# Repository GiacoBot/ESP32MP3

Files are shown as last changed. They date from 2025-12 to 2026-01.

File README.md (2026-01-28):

# **ESP32 MP3**

A self-built, portable MP3 player based on ESP32, combining a custom hardware design with an intuitive software interface. It reads music from an SD card, streams audio to any Bluetooth audio device, and is controlled via an OLED display and physical buttons.

<p align="center">
Project Photo
</p>

## **Introduction**

This project evolved from a simple software experiment. The initial version was merely a proof-of-concept for Bluetooth audio streaming from an ESP32. Driven by the desire to create a complete and presentable product, I designed and built a custom dev board, developing an entire graphical and physical user interface from scratch.

The result is a functional and integrated device, demonstrating expertise in both hardware design (PCB design with KiCad) and complex firmware development (modular C++ architecture).

## **✨ Key Features**

#### **Hardware**

*   **Custom Dev Board (Rev 1.1)**: Development board entirely designed with KiCad to house all components compactly and functionally.
*   **0.96" OLED Display**: Monochrome screen (SSD1306 128x64) for a clear, low-power user interface.
*   **Physical Controls**: Interface navigation is managed by 5 physical buttons (Up, Down, Left, Right, Enter).
*   **MicroSD Card Storage**: A MicroSD card slot allows easy loading and playback of your music library.
*   **Power Management**: Power circuit with support for Li-Ion batteries and USB-C charging.

#### **Software**

*   **Bluetooth Audio Streaming (A2DP Source)**: Connects to Bluetooth headphones and speakers for high-quality wireless playback.
*   **Multi-screen User Interface**:
    *   **Bluetooth Device Selection**: Scans for nearby audio devices and manages the connection.
    *   **Track Selection**: Allows browsing the complete playlist of songs on the SD Card.
    *   **Now Playing**: Displays track information (if available), song title, artist, and a progress bar.
    *   **Volume Control**: Adjusts the playback volume directly from the interface.
*   **Advanced Playlist Management**: Automatically scans the SD card on startup to find all `.mp3` files.
*   **Intuitive User Input**: Supports short press, long press, and auto-repeat of buttons for smooth and fast navigation.
*   **Modular Firmware Architecture**: The code is organized into specialized "Managers" (Display, Input, Bluetooth, Player), making the system scalable, maintainable, and easy to debug.

## **⚙️ Hardware Details**

The development board was designed in KiCad to integrate the ESP32 with all necessary modules. The design is optimized for manual assembly and for use as a portable device.

<p align="center">
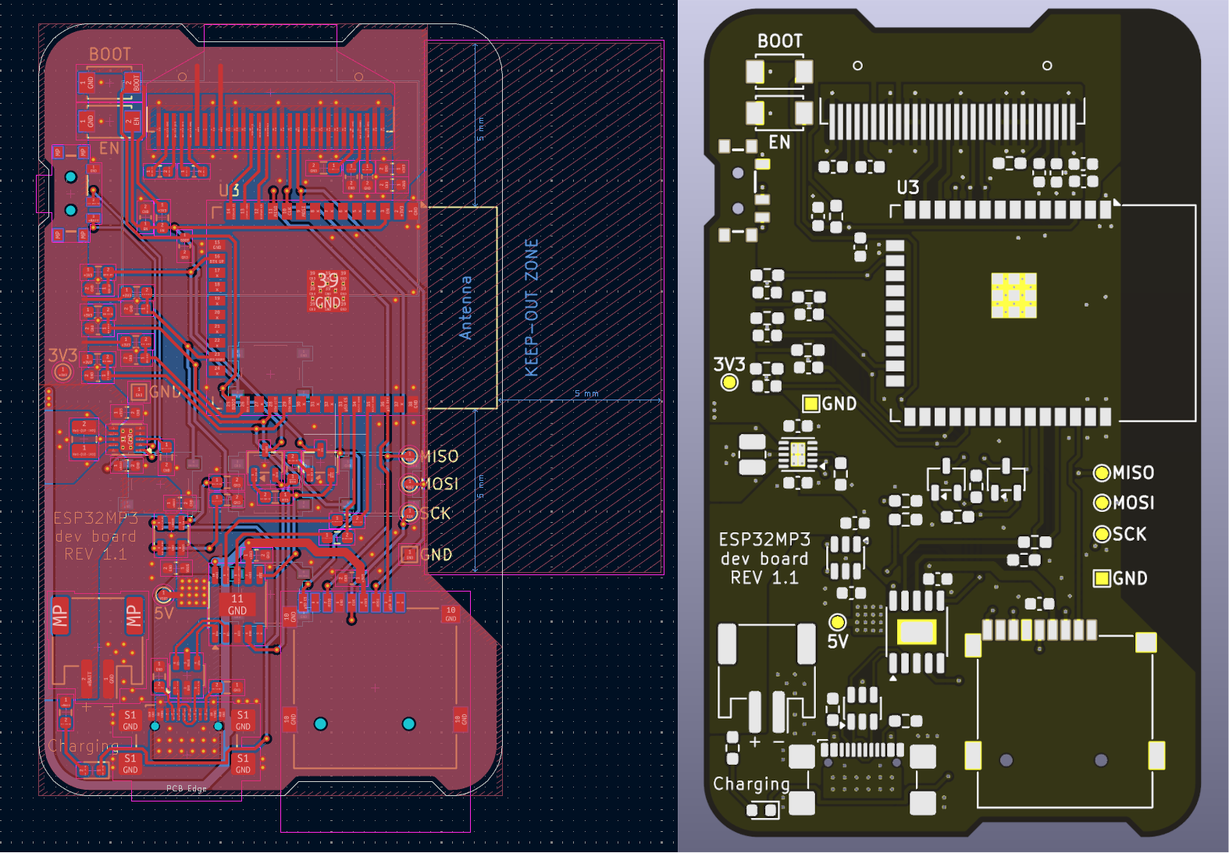
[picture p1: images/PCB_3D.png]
Project Photo

</p>

*   **Design Software**: KiCad
*   **Main Processor**: ESP32-WROOM-32E module
*   **Display**: 0.96 inch (128x64) SSD1306 I2C/SPI OLED module
*   **Storage**: Standard MicroSD card reader
*   **Hardware Repository**: KiCad project files (schematics, PCB, and libraries) are available in the [`/Hardware/devboard Rev1.1`](/Hardware/devboard%20Rev1.1/) folder.

## **💻 Software Details**

The firmware is developed using the Arduino framework within PlatformIO, which simplifies dependency management and compilation.

*   **Framework**: Arduino / PlatformIO
*   **Key Libraries**:
    *   **[`U8g2`](https://github.com/olikraus/U8g2)**: Excellent library for managing monochrome displays.
    *   **[`arduino-audio-tools`](https://github.com/pschatzmann/arduino-audio-tools)**: For the audio decoding and processing pipeline.
    *   **[`ESP32-A2DP`](https://github.com/pschatzmann/ESP32-A2DP)**: For implementing the Bluetooth A2DP Source stack.
    *   **[`arduino-libhelix`](https://github.com/pschatzmann/arduino-libhelix)**: Provides the MP3 decoder based on Helix.
*   **Architecture**: The heart of the software is a state machine that manages navigation between different screens (`AppScreen`). The logic is divided into independent manager classes that communicate via an event system (`InputEvent`) and shared states, ensuring high cohesion and low coupling between modules.

## **🚀 Getting Started**

> [!NOTE]  
> If you want to try a simplified version of the project, you can try the alpha version, a proof of concept that only requires a breakout module for the micro SD and an ESP32 board. Follow the `README` in the alpha version for instructions.

#### **1. Hardware Prerequisites**

*   The assembled Dev Board.
*   A MicroSD card formatted as FAT32 and loaded with `.mp3` files. Is required for the files to have a sample rate of 44100 Hz, use the following `ffmpeg` command to convert files if needed:

    ```bash
    ffmpeg -i input.mp3 -ar 44100 output.mp3
    ```
*   A USB-C cable to upload the firmware.

#### **2. Software Setup**

The project is designed to be compiled with PlatformIO in Visual Studio Code.

1.  **Install VS Code and PlatformIO**: Follow the [official PlatformIO guide](https://platformio.org/install/ide?install=vscode).
2.  **Clone the Repository**:
    ```bash
    git clone https://github.com/GiacoBot/ESP32MP3.git
    cd ESP32MP3
    ```
3.  **Initialize Submodules**: The audio libraries are included as Git submodules.
    ```bash
    git submodule update --init --recursive
    ```

#### **3. Compile and Upload**

1.  **Open the Project**: In VS Code, open the project folder. Make sure to open the `Software` subfolder.
> [!IMPORTANT]  
> The PlatformIO project is located within the `Software` folder. When you open this project in VS Code, make sure you open the `Software` directory, not the root of the repository, to ensure PlatformIO can find all the necessary files.

1.  **Change Board settings**: Modify the `src/settings.h` file to match your hardware configuration if necessary (e.g., pin assignments).
2.  **Compile and Upload**: Use the PlatformIO commands (down arrow on the status bar) to build and upload the firmware to the board.

## **📸 Gallery**

Various screenshots of the user interface:

<p align="center">
Project Photo
</p>

## **📜 License**

This project is released under the GPL-3.0 License. See the [LICENSE](LICENSE) file for more details.

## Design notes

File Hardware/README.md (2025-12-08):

# Hardware

This folder contains the hardware design files for the project's custom development board.
Each hardware revision is organized in its own subfolder to keep designs clean, traceable, and easy to reference.

### Dev boards

* **Devboard Rev1.0** – First prototype of the dev board. Includes schematics, PCB layout, Gerber files, and BOM.
* **Devboard Rev1.1** – Updated revision addressing small issues found in Rev1.0. Recommended for new builds.

The development board is a semi-finished prototype, created to also validate the electrical design of the battery-charging circuitry and the buck-boost voltage regulation stage.
Its purpose is to verify the power system and provide a convenient and compact development board.

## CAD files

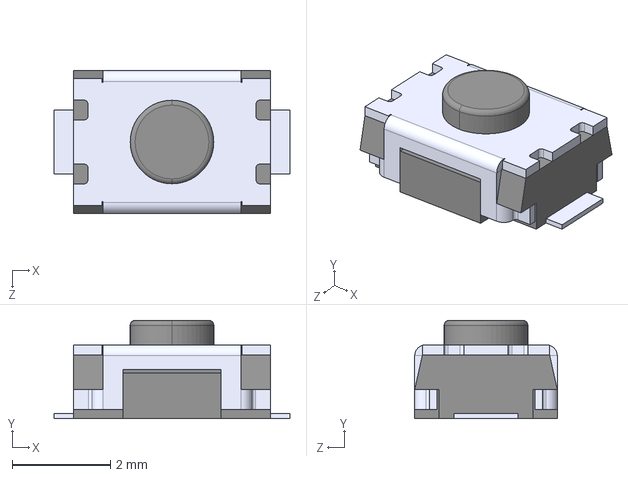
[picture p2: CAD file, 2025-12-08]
Hardware/devboard Rev1.1/Library.3dmodels/TS-1088-AR02016.step
4.80 x 2.00 x 2.90 mm

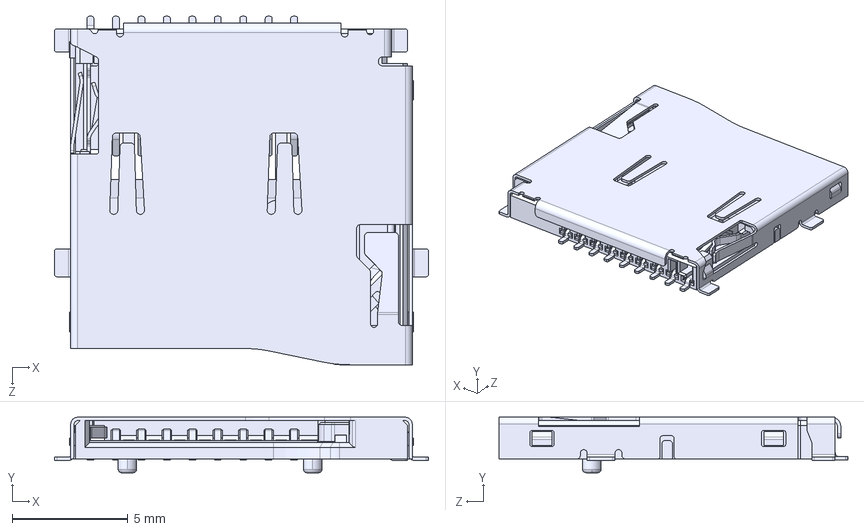
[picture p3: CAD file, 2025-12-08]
Hardware/devboard Rev1.1/Library.3dmodels/TF_PUSH.step
16.1 x 2.40 x 15.0 mm

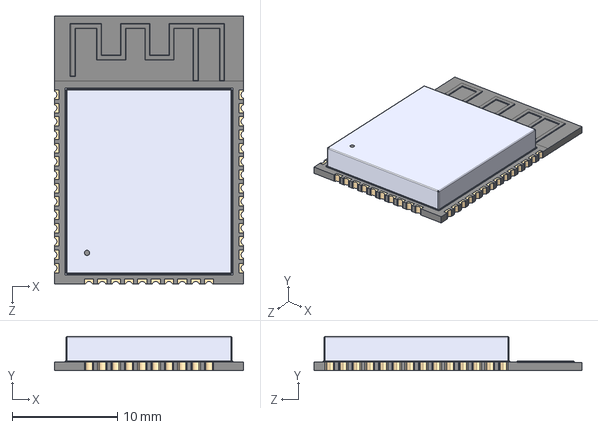
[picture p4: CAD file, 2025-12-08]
Hardware/devboard Rev1.1/Library.3dmodels/ESP32-WROOM-32E-N8.STEP
18.0 x 3.25 x 25.5 mm

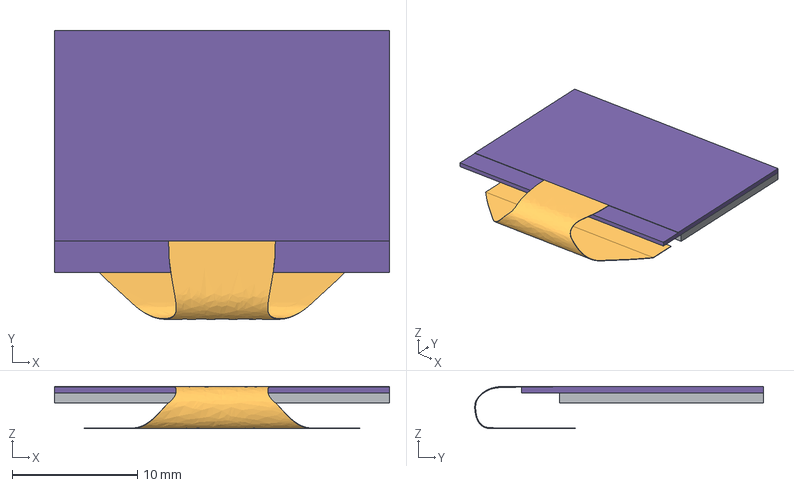
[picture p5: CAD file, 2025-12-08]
Hardware/devboard Rev1.1/Library.3dmodels/SSD1306_OLED_Display.step
26.7 x 23.0 x 3.35 mm

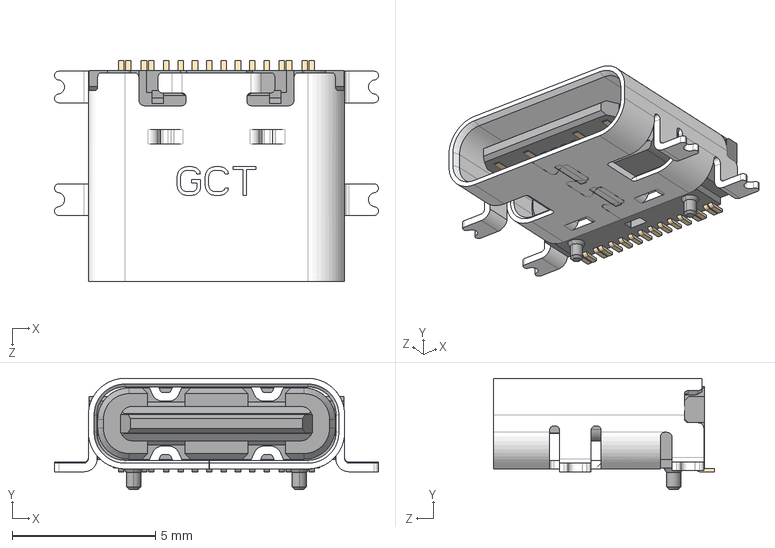
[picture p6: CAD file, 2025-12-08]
Hardware/devboard Rev1.1/Library.3dmodels/USBC.STEP
11.3 x 3.89 x 7.70 mm

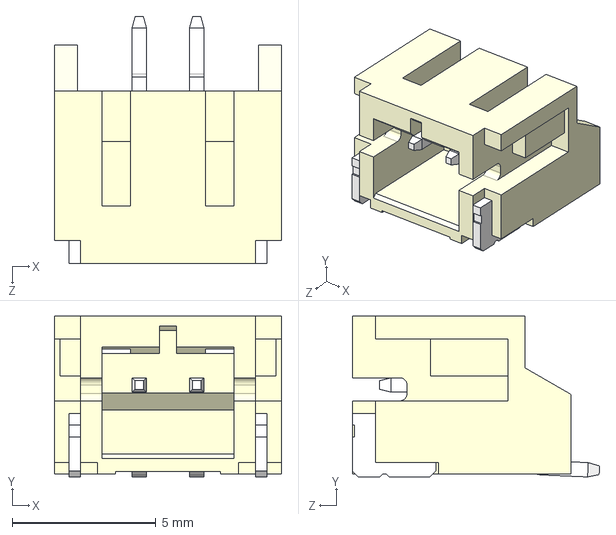
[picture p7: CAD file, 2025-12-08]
Hardware/devboard Rev1.1/Library.3dmodels/S2B-PH-SM4-TB.STEP
7.90 x 5.60 x 8.60 mm

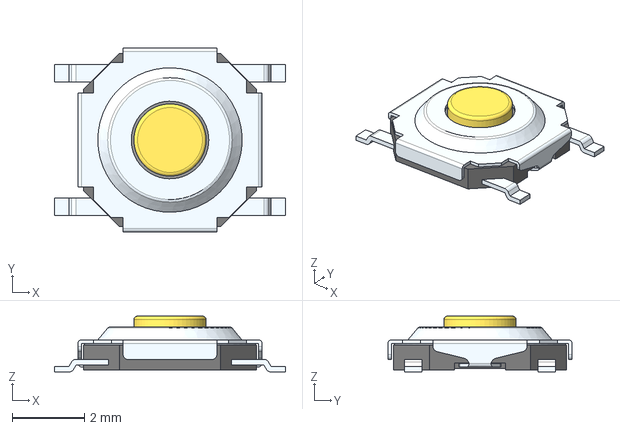
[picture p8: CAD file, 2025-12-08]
Hardware/devboard Rev1.1/Library.3dmodels/PTS526SK15SMTR2LFS.stp
6.40 x 5.10 x 1.55 mm

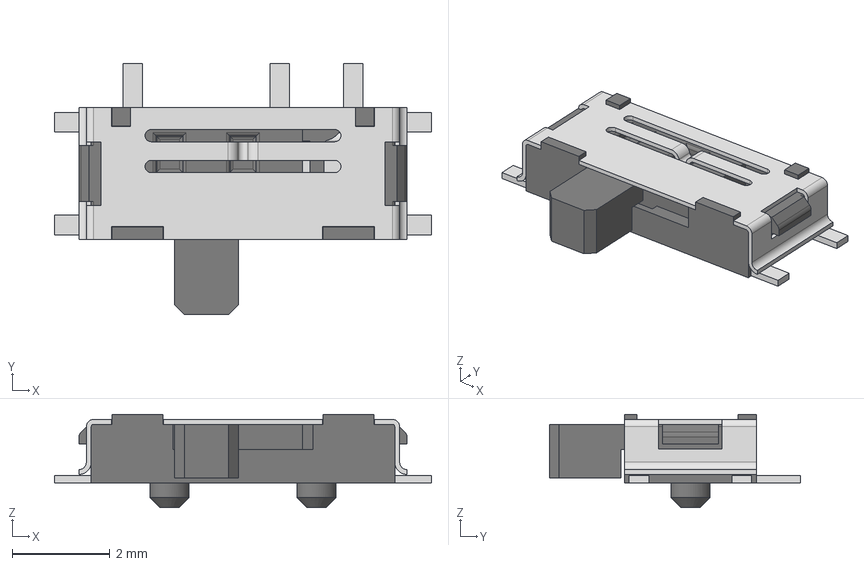
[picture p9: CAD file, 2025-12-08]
Hardware/devboard Rev1.1/Library.3dmodels/SWITCH SPDT.step
7.70 x 5.13 x 1.90 mm
Frame
Pin 4
Frame 1
Pin 1
Pin 2
Pin 3
Slider 1
Slider
Cover

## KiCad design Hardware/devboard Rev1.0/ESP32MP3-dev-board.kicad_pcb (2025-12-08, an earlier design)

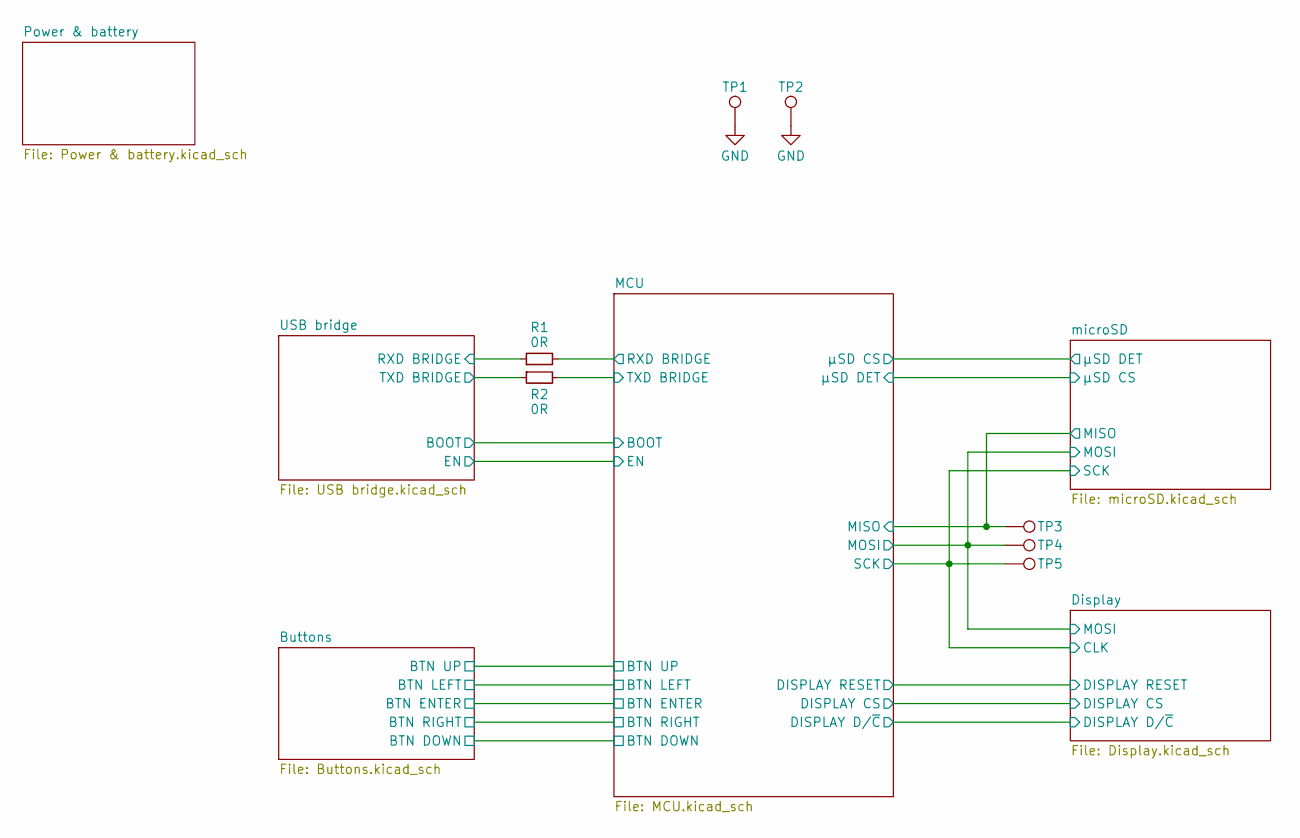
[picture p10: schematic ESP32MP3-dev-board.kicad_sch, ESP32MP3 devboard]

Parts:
R1, R2: 0R; R_0603_1608Metric_Pad0.98x0.95mm_HandSolder; Part Number YAGEO RC0603JR-070RL
TP1, TP2: GND; TestPoint_Pad_1.0x1.0mm
TP3: MISO; TestPoint_Pad_D1.0mm
TP4: MOSI; TestPoint_Pad_D1.0mm
TP5: SCK; TestPoint_Pad_D1.0mm

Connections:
/Display/CLK: TP5.1; also elsewhere on the board
/Display/MOSI: TP4.1; also elsewhere on the board
/MCU/MISO: TP3.1; also elsewhere on the board
/MCU/RXD BRIDGE: R1.2; also elsewhere on the board
/MCU/TXD BRIDGE: R2.2; also elsewhere on the board
/USB bridge/RXD BRIDGE: R1.1; also elsewhere on the board
/USB bridge/TXD BRIDGE: R2.1; also elsewhere on the board
GND: TP1.1, TP2.1; also elsewhere on the board

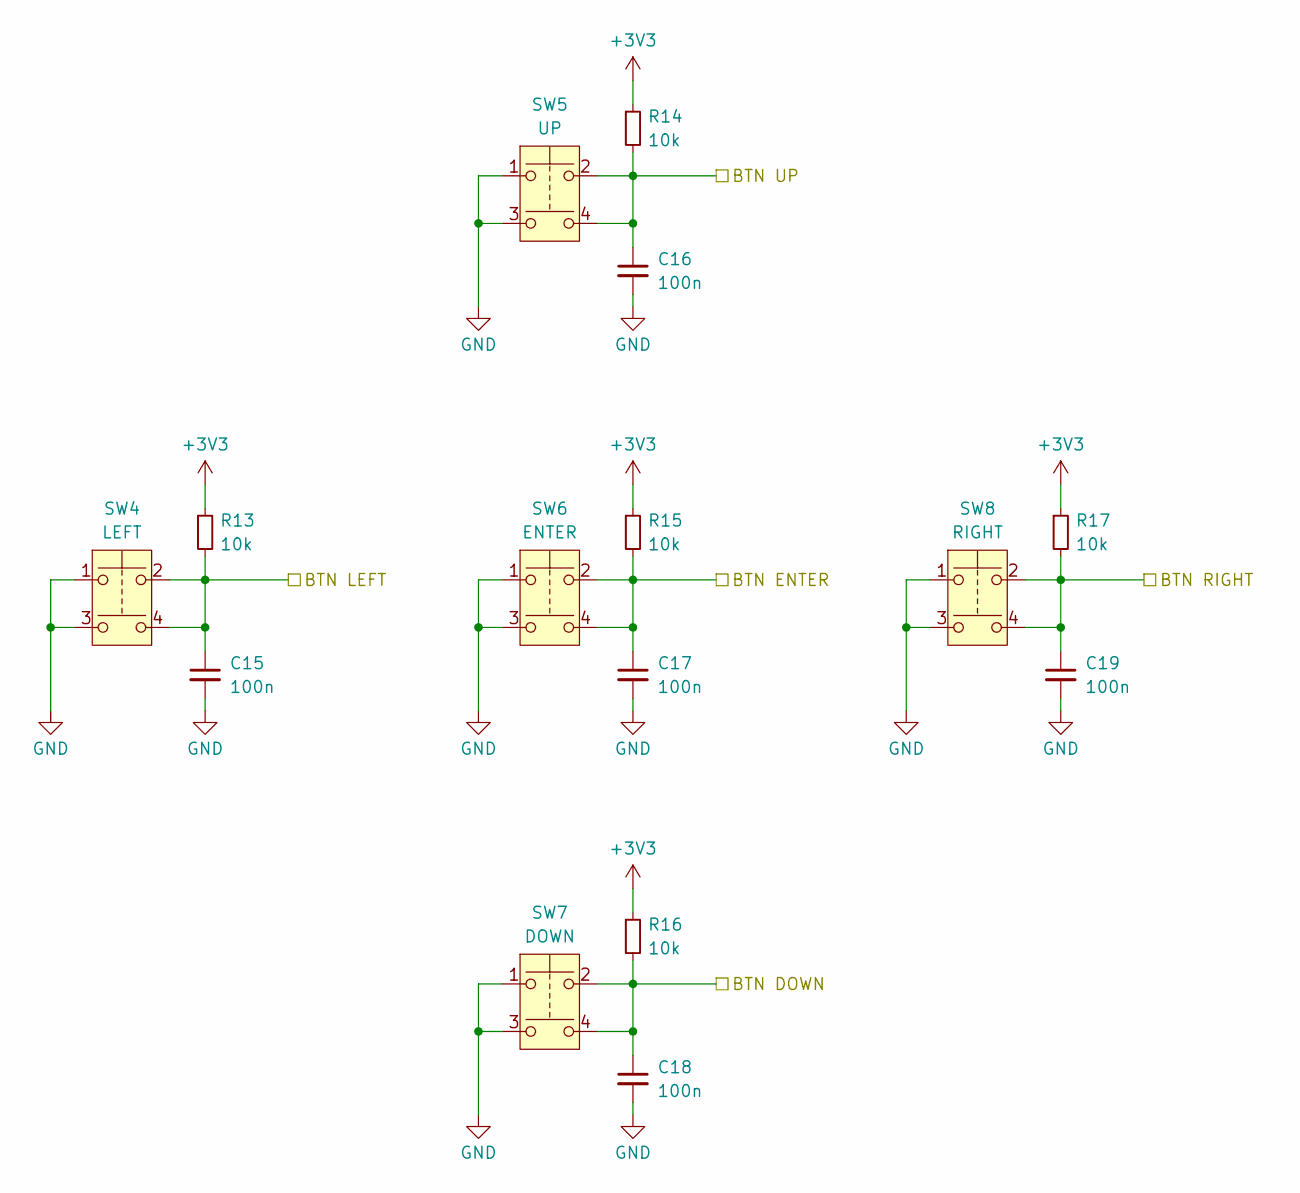
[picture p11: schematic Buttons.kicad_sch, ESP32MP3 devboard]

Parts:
C15, C16, C17, C18, C19: 100n; C_0603_1608Metric; Part Number YAGEO CC0603KRX7R9BB104
R13, R14, R15, R16, R17: 10k; R_0603_1608Metric_Pad0.98x0.95mm_HandSolder; Part Number YAGEO RC0603FR-0710KL
SW4: LEFT; PTS526SM15SMTR2LFS; Part Number C&K PTS526SK15SMTR2LFS
SW5: UP; PTS526SM15SMTR2LFS; Part Number C&K PTS526SK15SMTR2LFS
SW6: ENTER; PTS526SM15SMTR2LFS; Part Number C&K PTS526SK15SMTR2LFS
SW7: DOWN; PTS526SM15SMTR2LFS; Part Number C&K PTS526SK15SMTR2LFS
SW8: RIGHT; PTS526SM15SMTR2LFS; Part Number C&K PTS526SK15SMTR2LFS

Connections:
+3V3: R13.1, R14.1, R15.1, R16.1, R17.1; also elsewhere on the board
/Buttons/BTN DOWN: C18.1, R16.2, SW7.2, SW7.4; also elsewhere on the board
/Buttons/BTN ENTER: C17.1, R15.2, SW6.2, SW6.4; also elsewhere on the board
/Buttons/BTN LEFT: C15.1, R13.2, SW4.2, SW4.4; also elsewhere on the board
/Buttons/BTN RIGHT: C19.1, R17.2, SW8.2, SW8.4; also elsewhere on the board
/Buttons/BTN UP: C16.1, R14.2, SW5.2, SW5.4; also elsewhere on the board
GND: C15.2, C16.2, C17.2, C18.2, C19.2, SW4.1, SW4.3, SW5.1, SW5.3, SW6.1, SW6.3, SW7.1, SW7.3, SW8.1, SW8.3; also elsewhere on the board

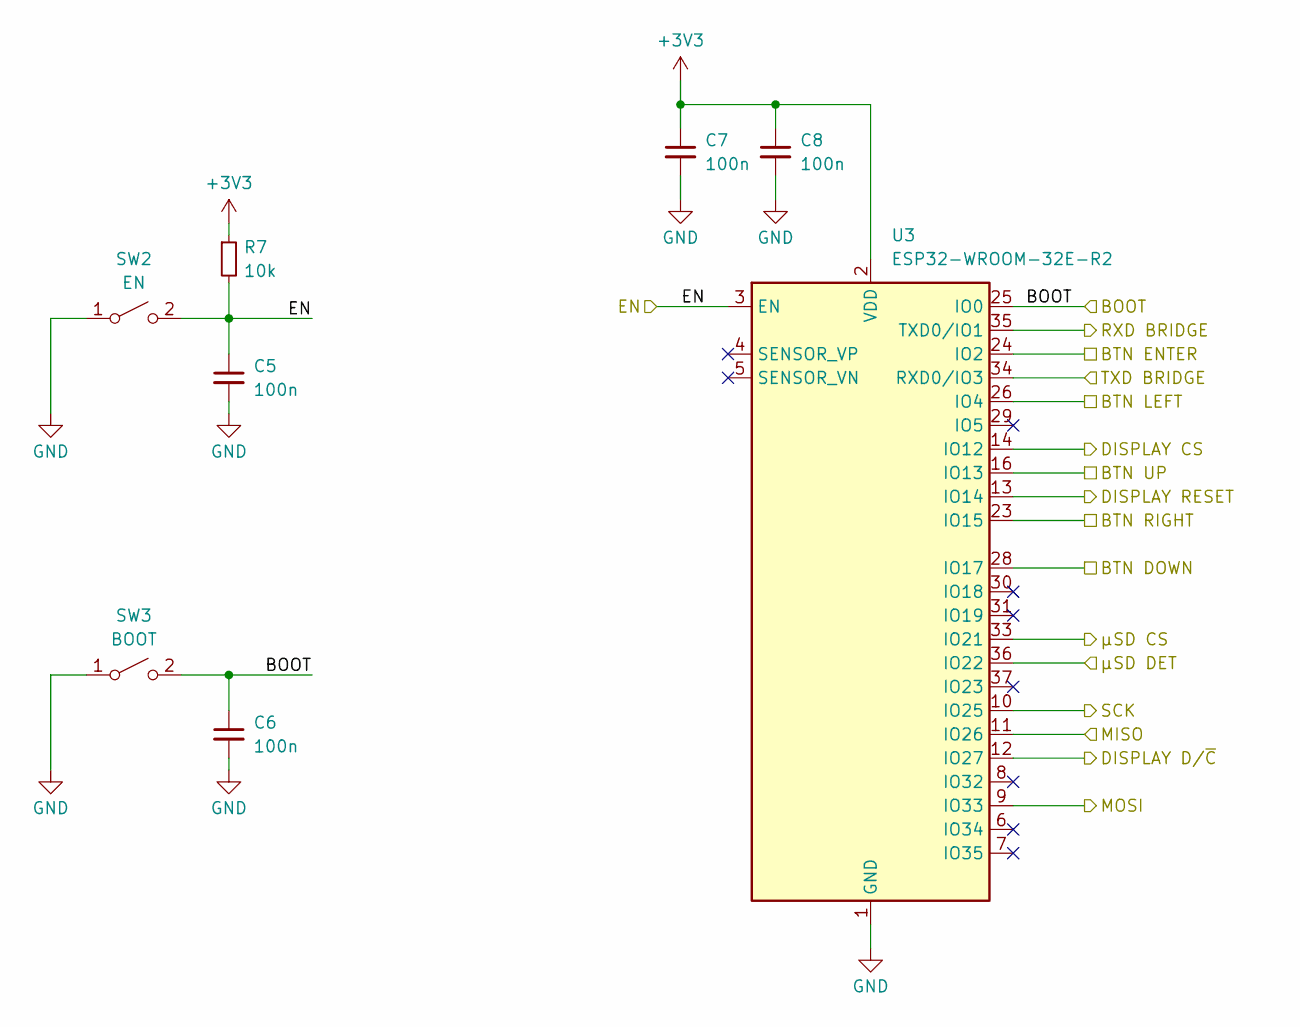
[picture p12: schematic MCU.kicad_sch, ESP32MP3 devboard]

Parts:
C5, C6, C7, C8: 100n; C_0603_1608Metric; Part Number YAGEO CC0603KRX7R9BB104
R7: 10k; R_0603_1608Metric_Pad0.98x0.95mm_HandSolder; Part Number YAGEO RC0603FR-0710KL
SW2: EN; SW_TS-1088-AR02016; Part Number XUNPU TS-1088-AR02016
SW3: BOOT; SW_TS-1088-AR02016; Part Number XUNPU TS-1088-AR02016
U3: ESP32-WROOM-32E-R2; ESP32-WROOM-32D; Part Number ESPRESSIF ESP32-WROOM-32E-N8R2

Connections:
+3V3: C7.1, C8.1, R7.1, U3.2 (VDD); also elsewhere on the board
/Buttons/BTN DOWN: U3.28 (IO17); also elsewhere on the board
/Buttons/BTN ENTER: U3.24 (IO2); also elsewhere on the board
/Buttons/BTN LEFT: U3.26 (IO4); also elsewhere on the board
/Buttons/BTN RIGHT: U3.23 (IO15); also elsewhere on the board
/Buttons/BTN UP: U3.16 (IO13); also elsewhere on the board
/Display/CLK: U3.10 (IO25); also elsewhere on the board
/Display/DISPLAY CS: U3.14 (IO12); also elsewhere on the board
/Display/DISPLAY D/~C: U3.12 (IO27); also elsewhere on the board
/Display/DISPLAY RESET: U3.13 (IO14); also elsewhere on the board
/Display/MOSI: U3.9 (IO33); also elsewhere on the board
/MCU/BOOT: C6.1, SW3.2 (B), U3.25 (IO0); also elsewhere on the board
/MCU/EN: C5.1, R7.2, SW2.2 (B), U3.3 (EN); also elsewhere on the board
/MCU/MISO: U3.11 (IO26); also elsewhere on the board
/MCU/RXD BRIDGE: U3.35 (TXD0/IO1); also elsewhere on the board
/MCU/TXD BRIDGE: U3.34 (RXD0/IO3); also elsewhere on the board
/MCU/µSD CS: U3.33 (IO21); also elsewhere on the board
/MCU/µSD DET: U3.36 (IO22); also elsewhere on the board
GND: C5.2, C6.2, C7.2, C8.2, SW2.1 (A), SW3.1 (A), U3.1 (GND), U3.15 (GND), U3.38 (GND), U3.39 (GND); also elsewhere on the board

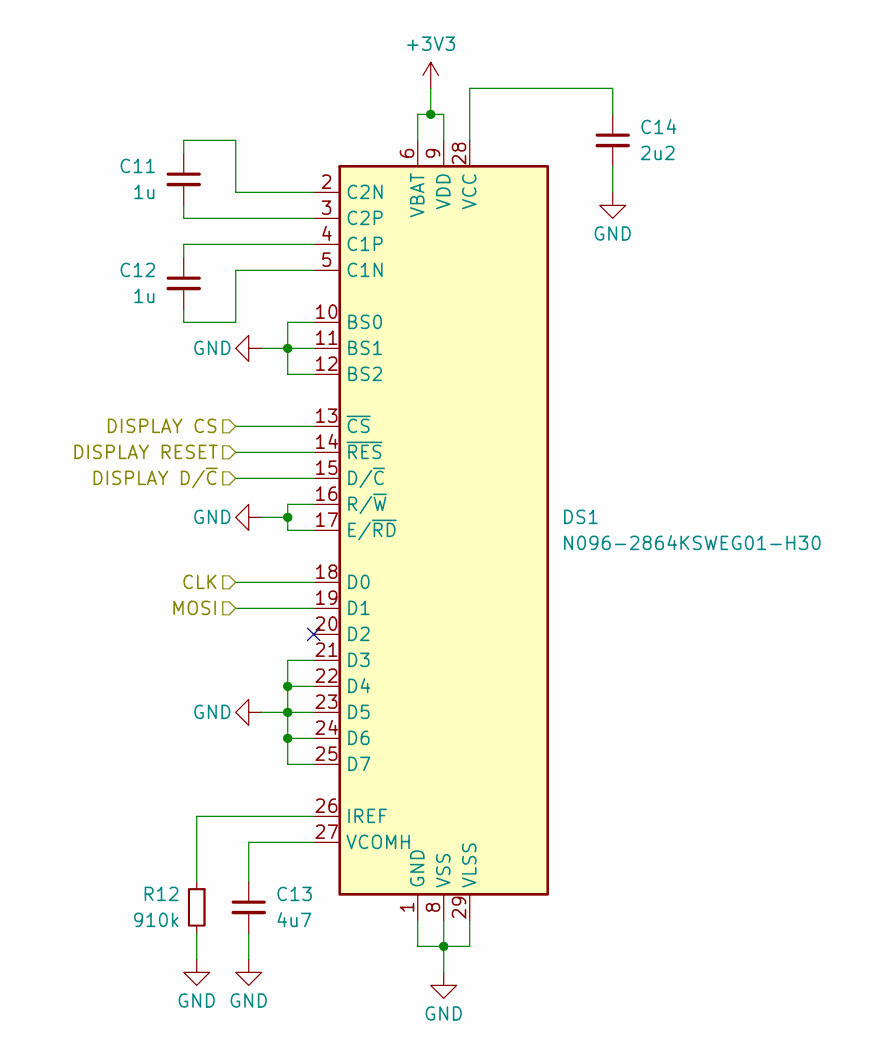
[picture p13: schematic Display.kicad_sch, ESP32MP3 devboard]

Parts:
C11, C12: 1u; C_0603_1608Metric; Part Number Samsung Electro-Mechanics CL10B105KA8NN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
C13: 4u7; C_0603_1608Metric; Part Number Samsung Electro-Mechanics CL10A475KA8NQ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
C14: 2u2; C_0603_1608Metric; Part Number muRata GRM188Z71E225KE43D
DS1: N096-2864KSWEG01-H30; Part Number Wisevision N096-2864KSWEG01-H30
R12: 910k; R_0603_1608Metric_Pad0.98x0.95mm_HandSolder; Part Number YAGEO RC0603FR-07910KL

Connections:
+3V3: DS1.6 (VBAT), DS1.9 (VDD); also elsewhere on the board
/Display/CLK: DS1.18 (D0); also elsewhere on the board
/Display/DISPLAY CS: DS1.13 (~CS); also elsewhere on the board
/Display/DISPLAY D/~C: DS1.15 (D/~C); also elsewhere on the board
/Display/DISPLAY RESET: DS1.14 (~RES); also elsewhere on the board
/Display/MOSI: DS1.19 (D1); also elsewhere on the board
GND: C13.2, C14.2, DS1.1 (GND), DS1.8 (VSS), DS1.10 (BS0), DS1.11 (BS1), DS1.12 (BS2), DS1.16 (R/~W), DS1.17 (E/~RD), DS1.21 (D3), DS1.22 (D4), DS1.23 (D5), DS1.24 (D6), DS1.25 (D7), DS1.29 (VLSS), DS1.30 (GND), R12.2; also elsewhere on the board
unnamed: C12.2, DS1.5 (C1N)
unnamed: C12.1, DS1.4 (C1P)
unnamed: C11.1, DS1.2 (C2N)
unnamed: C11.2, DS1.3 (C2P)
unnamed: DS1.26 (IREF), R12.1
unnamed: C14.1, DS1.28 (VCC)
unnamed: C13.1, DS1.27 (VCOMH)

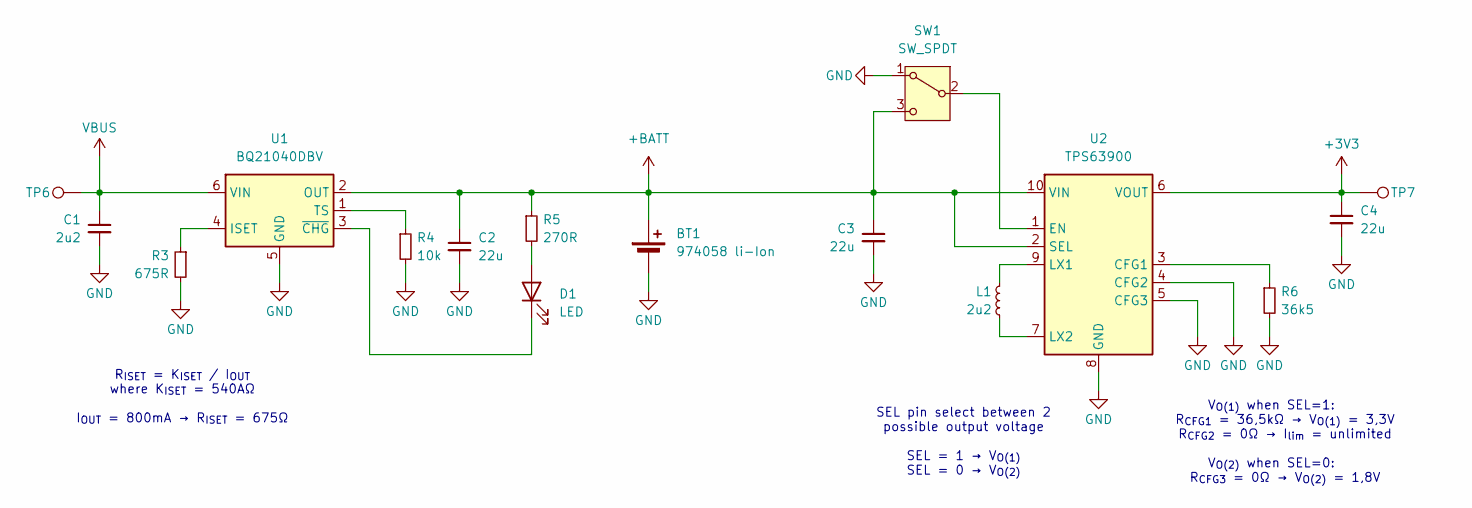
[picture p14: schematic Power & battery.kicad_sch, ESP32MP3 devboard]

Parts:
BT1: 974058 li-Ion; JST_PH_S2B-PH-SM4-TB_1x02-1MP_P2.00mm_Horizontal; Part Number JST S2B-PH-SM4-TB(LF)(SN)
C1: 2u2; C_0603_1608Metric; Part Number muRata GRM188Z71E225KE43D
C2, C3, C4: 22u; C_0603_1608Metric; Part Number Samsung Electro-Mechanics CL10A226MP8NU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
D1: LED; LED_0603_1608Metric; Part Number EVERLIGHT 19-219/GHC-YR2T1B5Y/3T
L1: 2u2; L_1008_2520Metric; Part Number ZE ZEMS252012-2R2M
R3: 675R; R_0603_1608Metric_Pad0.98x0.95mm_HandSolder; Part Number YAGEO RC0603FR-07680RL
R4: 10k; R_0603_1608Metric_Pad0.98x0.95mm_HandSolder; Part Number YAGEO RC0603FR-0710KL
R5: 270R; R_0603_1608Metric_Pad0.98x0.95mm_HandSolder; Part Number YAGEO RC0603FR-07270RL
R6: 36k5; R_0603_1608Metric_Pad0.98x0.95mm_HandSolder; Part Number YAGEO RT0603BRE0736K5L
SW1: SW_SPDT; MK-12C02-G015; Part Number G-Switch MK-12C02-G015
TP6: 5V; TestPoint_Pad_D1.0mm
TP7: 3V3; TestPoint_Pad_D1.0mm
U1: BQ21040DBV; SOT-23-6; Part Number TI BQ21040DBVR
U2: TPS63900; WSON-10-1EP_2.5x2.5mm_P0.5mm_EP1.2x2mm_ThermalVias; Part Number TI TPS63900DSKR

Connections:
+3V3: C4.1, TP7.1, U2.6 (VOUT); also elsewhere on the board
+BATT: BT1.2 (+), C2.1, C3.1, R5.1, SW1.3 (C), U1.2 (OUT), U2.2 (SEL), U2.10 (VIN)
GND: BT1.1 (-), C1.2, C2.2, C3.2, C4.2, R3.2, R4.2, R6.2, SW1.1 (A), U1.5 (GND), U2.4 (CFG2), U2.5 (CFG3), U2.8 (GND), U2.11 (GND); also elsewhere on the board
unnamed: D1.2 (A), R5.2
unnamed: D1.1 (K), U1.3 (~CHG)
unnamed: SW1.2 (B), U2.1 (EN)
unnamed: R3.1, U1.4 (ISET)
unnamed: R4.1, U1.1 (TS)
unnamed: R6.1, U2.3 (CFG1)
unnamed: L1.1, U2.9 (LX1)
unnamed: L1.2, U2.7 (LX2)
VBUS: C1.1, TP6.1, U1.6 (VIN); also elsewhere on the board

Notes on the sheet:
R_{ISET} = K_{ISET} / I_{OUT} where K_{ISET} = 540AΩ I_{OUT} = 800mA → R_{ISET} = 675Ω
SEL pin select between 2 possible output voltage SEL = 1 → V_{O(1)} SEL = 0 → V_{O(2)}
V_{O(1)} when SEL=1: R_{CFG1} = 36,5kΩ → V_{O(1)} = 3,3V R_{CFG2} = 0Ω → I_{lim} = unlimited V_{O(2)} when SEL=0: R_{CFG3} = 0Ω → V_{O(2)} = 1,8V

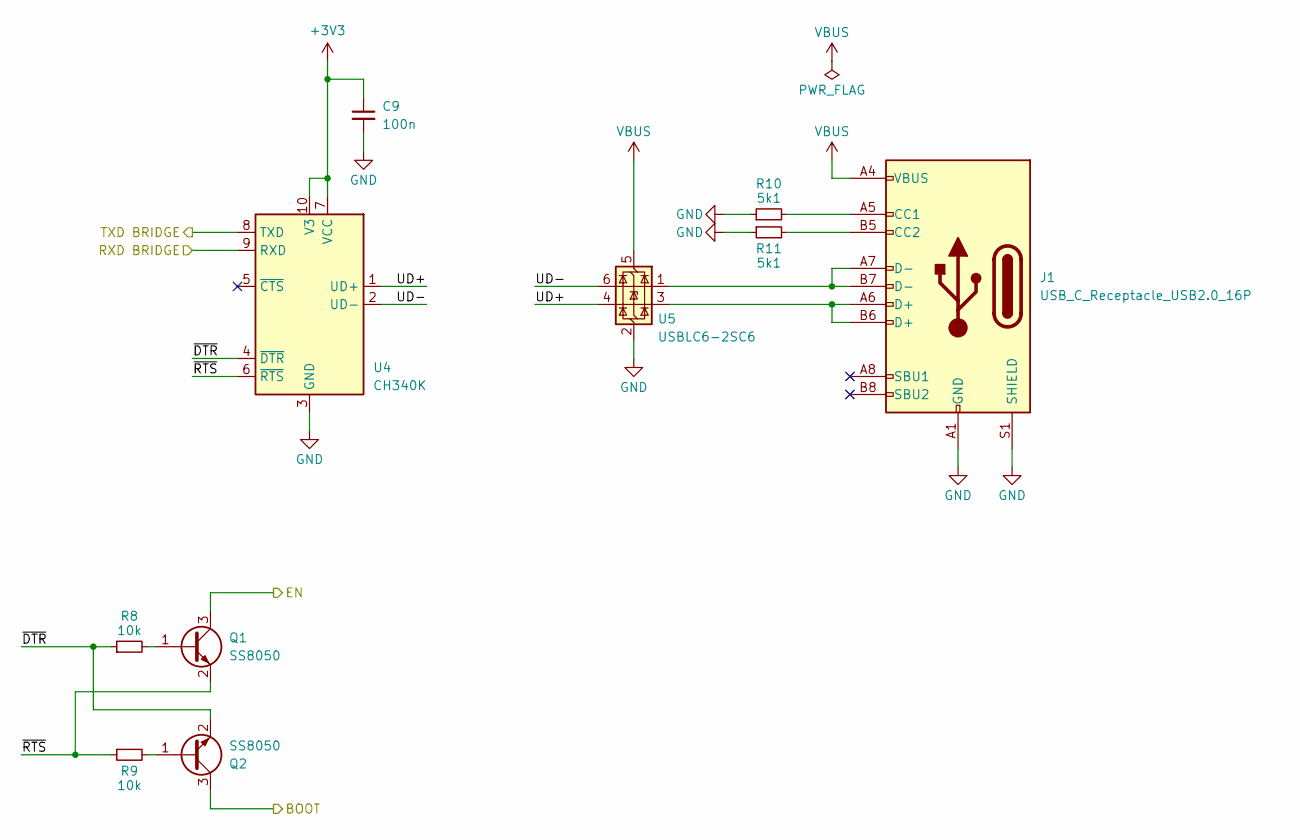
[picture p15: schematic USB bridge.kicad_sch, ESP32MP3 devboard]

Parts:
C9: 100n; C_0603_1608Metric; Part Number YAGEO CC0603KRX7R9BB104
J1: USB_C_Receptacle_USB2.0_16P; USB_C_Receptacle_GCT_USB4110; Part Number DEALON USB-TYPE-C-020
Q1, Q2: SS8050; SOT-23-3; Part Number Chao He SS8050
R8, R9: 10k; R_0603_1608Metric_Pad0.98x0.95mm_HandSolder; Part Number YAGEO RC0603FR-0710KL
R10, R11: 5k1; R_0603_1608Metric_Pad0.98x0.95mm_HandSolder; Part Number YAGEO RC0603FR-075K1L
U4: CH340K; SSOP-10-1EP_3.9x4.9mm_P1mm_EP2.1x3.3mm; Part Number WCH CH340K
U5: USBLC6-2SC6; SOT-23-6; Part Number TECH PUBLIC USBLC6-2SC6

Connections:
+3V3: C9.1, U4.7 (VCC), U4.10 (V3); also elsewhere on the board
/MCU/BOOT: Q2.3 (C); also elsewhere on the board
/MCU/EN: Q1.3 (C); also elsewhere on the board
/USB bridge/RXD BRIDGE: U4.9 (RXD); also elsewhere on the board
/USB bridge/TXD BRIDGE: U4.8 (TXD); also elsewhere on the board
/USB bridge/UD+: U4.1 (UD+), U5.4 (I/O2)
/USB bridge/UD-: U4.2 (UD-), U5.6 (I/O1)
/USB bridge/~DTR: Q2.2 (E), R8.1, U4.4 (~DTR)
/USB bridge/~RTS: Q1.2 (E), R9.1, U4.6 (~RTS)
GND: C9.2, J1.A1 (GND), J1.A12 (GND), J1.B1 (GND), J1.B12 (GND), J1.S1 (SHIELD), R10.1, R11.1, U4.3 (GND), U4.11 (GND), U5.2 (GND); also elsewhere on the board
unnamed: J1.A5 (CC1), R10.2
unnamed: J1.B5 (CC2), R11.2
unnamed: J1.A6 (D+), J1.B6 (D+), U5.3 (I/O2)
unnamed: J1.A7 (D-), J1.B7 (D-), U5.1 (I/O1)
unnamed: Q1.1 (B), R8.2
unnamed: Q2.1 (B), R9.2
VBUS: J1.A4 (VBUS), J1.A9 (VBUS), J1.B4 (VBUS), J1.B9 (VBUS), U5.5 (VBUS); also elsewhere on the board

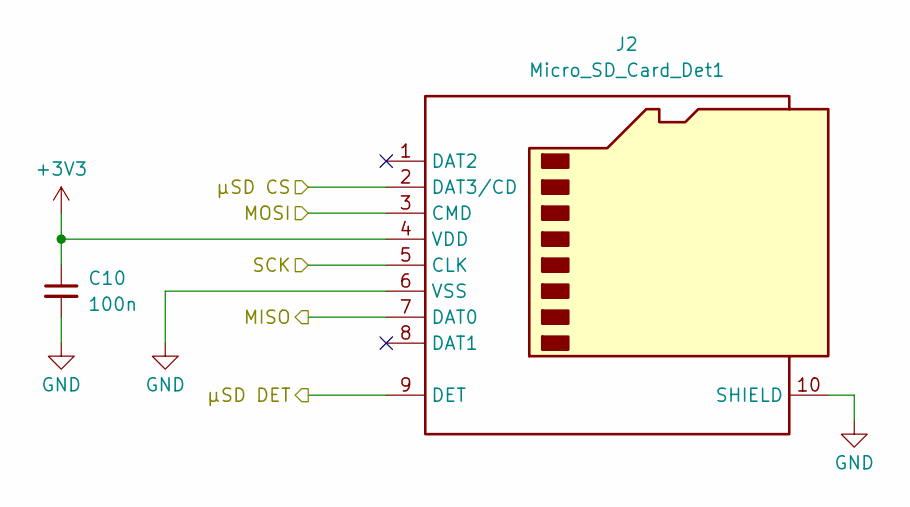
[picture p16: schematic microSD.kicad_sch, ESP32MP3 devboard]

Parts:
C10: 100n; C_0603_1608Metric; Part Number YAGEO CC0603KRX7R9BB104
J2: Micro_SD_Card_Det1; TF PUSH; Part Number SHOU HAN TF PUSH

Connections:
+3V3: C10.1, J2.4 (VDD); also elsewhere on the board
/Display/CLK: J2.5 (CLK); also elsewhere on the board
/Display/MOSI: J2.3 (CMD); also elsewhere on the board
/MCU/MISO: J2.7 (DAT0); also elsewhere on the board
/MCU/µSD CS: J2.9 (DET); also elsewhere on the board
/MCU/µSD DET: J2.2 (DAT3/CD); also elsewhere on the board
GND: C10.2, J2.6 (VSS), J2.10 (SHIELD); also elsewhere on the board

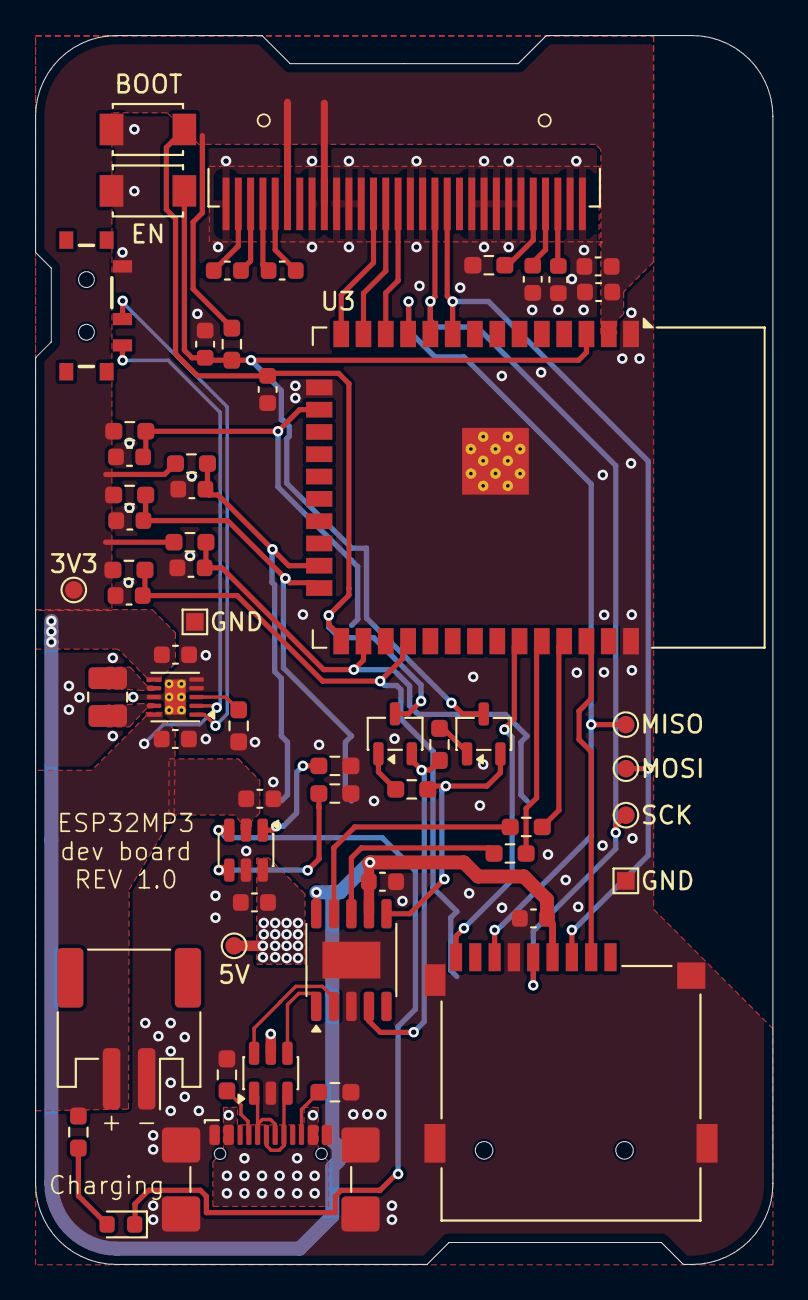
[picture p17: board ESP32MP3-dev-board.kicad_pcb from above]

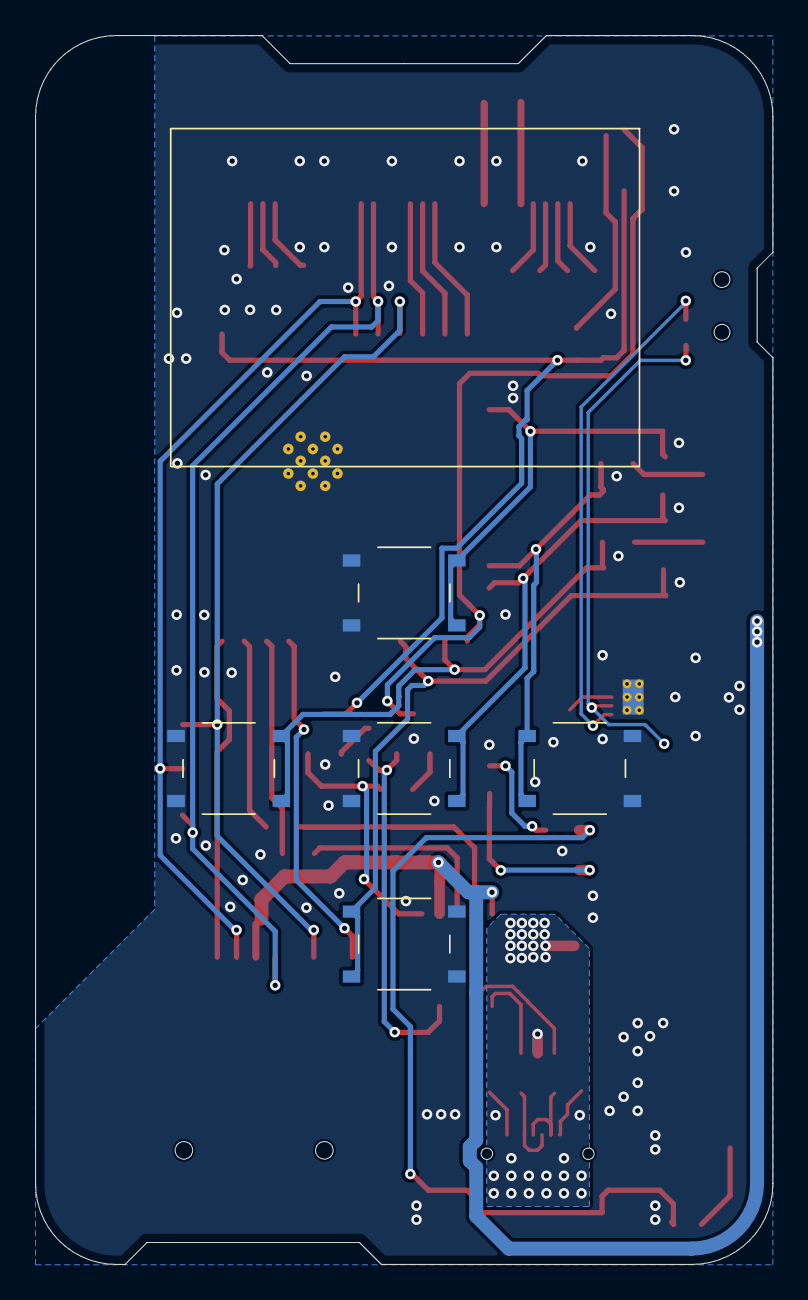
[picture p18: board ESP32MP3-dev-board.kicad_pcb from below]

Board: 2 copper layers, 42.0 x 70.0 mm, 64 parts (5 on the bottom side), 48 nets.

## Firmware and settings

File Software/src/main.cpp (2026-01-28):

#include <Arduino.h>
#include <SPI.h>
#include <SD.h>

#include "settings.h"
#include "MusicPlayer.h"
#include "PlaylistManager.h" 
#include "BluetoothManager.h"
#include "AudioProcessor.h"
#include "InputManager.h"
#include "DisplayManager.h"
#include "AppState.h"
#include "InputEvents.h"

// --- Global Objects ---
MusicPlayer music_player;
PlaylistManager playlist_manager(MUSIC_ROOT);
BluetoothManager bluetooth_manager;
AudioProcessor audio_processor;
InputManager input_manager;
DisplayManager display_manager;

// --- Global UI State ---
AppScreen current_screen = AppScreen::SCREEN_BLUETOOTH_SELECTION;
int bt_menu_selected = 0;
int bt_menu_offset = 0;
int playlist_menu_selected = 0;
int playlist_menu_offset = 0;

void setup() {
    Serial.begin(SERIAL_BAUD_RATE);
    while (!Serial) {}
    
    Serial.println("ESP32 Bluetooth MP3 Player Starting...");
    
    SPI.begin(SPI_SCK, SPI_MISO, SPI_MOSI);
    SPI.setFrequency(10e6);
    SPI.setDataMode(SPI_MODE0);

    display_manager.initialize();
    display_manager.setMusicPlayer(&music_player);
    display_manager.setBluetoothManager(&bluetooth_manager);
    display_manager.setPlaylistManager(&playlist_manager);
    
    if (!SD.begin(SD_CS_PIN)) {
        Serial.println("SD card initialization failed!");
        return;
    }
    Serial.println("SD card initialized successfully");
    
    if (!playlist_manager.scanForMP3Files() || playlist_manager.getTrackCount() == 0) {
        Serial.println("No MP3 files found on SD card!");
    }
    
    bluetooth_manager.setMusicPlayer(&music_player);
    if (!bluetooth_manager.initialize("ESP32_MP3_Player")) {
        Serial.println("Failed to initialize Bluetooth");
        return;
    }
    
    input_manager.initialize();
    
    Serial.println("System ready! Starting Bluetooth discovery...");
    bluetooth_manager.startDiscovery();
}

void loop() {
    InputEvent event = input_manager.handleInputs();

    // --- State Machine Logic ---
    switch (current_screen) {
        case AppScreen::SCREEN_BLUETOOTH_SELECTION: {
            // --- Logic for this screen depends on connection state ---
            if (bluetooth_manager.isConnecting()) {
                // --- CONNECTING STATE ---
                // While connecting, the screen is non-interactive. Only allow screen switching and ENTER to cancel.
                switch (event) {
                    case InputEvent::INPUT_EVENT_ENTER:
                        bluetooth_manager.disconnect(); // Disconnecting aborts the connection attempt
                        break;
                    case InputEvent::INPUT_EVENT_RIGHT:
                        current_screen = AppScreen::SCREEN_TRACK_SELECTION;
                        break;
                    case InputEvent::INPUT_EVENT_LEFT:
                        current_screen = AppScreen::SCREEN_VOLUME_CONTROL;
                        break;
                    default: break;
                }
            } else if (bluetooth_manager.isConnected()) {
                // --- CONNECTED STATE ---
                // In this state, there's only one option: Disconnect.
                bt_menu_selected = 0; // Always select the "Disconnect" button
                
                switch (event) {
                    case InputEvent::INPUT_EVENT_ENTER:
                        bluetooth_manager.disconnect();
                        // After disconnecting, discovery will start automatically (handled in BluetoothManager)
                        break;
                    // In connected state, other navigation buttons do nothing for this screen
                    case InputEvent::INPUT_EVENT_RIGHT:
                        current_screen = AppScreen::SCREEN_TRACK_SELECTION;
                        break;
                    case InputEvent::INPUT_EVENT_LEFT:
                        current_screen = AppScreen::SCREEN_VOLUME_CONTROL;
                        break;
                    default: break;
                }
            } else {
                // --- DISCONNECTED STATE ---
                // In this state, we are browsing the list of discovered devices
                int device_count = bluetooth_manager.getDiscoveredDevices().size();
                switch (event) {
                    case InputEvent::INPUT_EVENT_UP:
                    case InputEvent::INPUT_EVENT_UP_LONG_PRESS:
                    case InputEvent::INPUT_EVENT_UP_REPEAT:
                        if (device_count > 0) {
                            bt_menu_selected = (bt_menu_selected > 0) ? bt_menu_selected - 1 : device_count - 1;
                        }
                        break;
                    case InputEvent::INPUT_EVENT_DOWN:
                    case InputEvent::INPUT_EVENT_DOWN_LONG_PRESS:
                    case InputEvent::INPUT_EVENT_DOWN_REPEAT:
                        if (device_count > 0) {
                            bt_menu_selected = (bt_menu_selected < device_count - 1) ? bt_menu_selected + 1 : 0;
                        }
                        break;
                    case InputEvent::INPUT_EVENT_RIGHT:
                        current_screen = AppScreen::SCREEN_TRACK_SELECTION;
                        break;
                    case InputEvent::INPUT_EVENT_LEFT:
                        current_screen = AppScreen::SCREEN_VOLUME_CONTROL;
                        break;
                    case InputEvent::INPUT_EVENT_ENTER:
                        if (device_count > 0 && bt_menu_selected < device_count) {
                            const auto& devices = bluetooth_manager.getDiscoveredDevices();
                            bluetooth_manager.connect(devices[bt_menu_selected]);
                            // Screen will change to "Connecting..." automatically on next display update
                        }
                        break;
                    default: break;
                }
            }
            // Update the display manager with the current selection state
            display_manager.setBluetoothMenuState(bt_menu_selected, bt_menu_offset);
            break;
        }

        case AppScreen::SCREEN_TRACK_SELECTION: {
            int track_count = playlist_manager.getTrackCount();
            switch (event) {
                case InputEvent::INPUT_EVENT_UP:
                case InputEvent::INPUT_EVENT_UP_LONG_PRESS:
                case InputEvent::INPUT_EVENT_UP_REPEAT:
                    if (track_count > 0) {
                        playlist_menu_selected = (playlist_menu_selected > 0) ? playlist_menu_selected - 1 : track_count - 1;
                    }
                    break;
                case InputEvent::INPUT_EVENT_DOWN:
                case InputEvent::INPUT_EVENT_DOWN_LONG_PRESS:
                case InputEvent::INPUT_EVENT_DOWN_REPEAT:
                    if (track_count > 0) {
                        playlist_menu_selected = (playlist_menu_selected < track_count - 1) ? playlist_menu_selected + 1 : 0;
                    }
                    break;
                case InputEvent::INPUT_EVENT_RIGHT:
                    current_screen = AppScreen::SCREEN_NOW_PLAYING;
                    break;
                case InputEvent::INPUT_EVENT_LEFT:
                    current_screen = AppScreen::SCREEN_BLUETOOTH_SELECTION;
                    break;
                case InputEvent::INPUT_EVENT_ENTER:
                    if (track_count > 0 && playlist_menu_selected < track_count) {
                        music_player.executeCommand(PlayerCommand::PLAY_TRACK, playlist_menu_selected);
                        current_screen = AppScreen::SCREEN_NOW_PLAYING;
                    }
                    break;
                default: break;
            }
            display_manager.setPlaylistMenuState(playlist_menu_selected, playlist_menu_offset);
            break;
        }

        case AppScreen::SCREEN_NOW_PLAYING: {
            switch (event) {
                case InputEvent::INPUT_EVENT_UP:
                case InputEvent::INPUT_EVENT_UP_LONG_PRESS:
                case InputEvent::INPUT_EVENT_UP_REPEAT:
                    music_player.executeCommand(PlayerCommand::PREV_TRACK);
                    break;
                case InputEvent::INPUT_EVENT_DOWN:
                case InputEvent::INPUT_EVENT_DOWN_LONG_PRESS:
                case InputEvent::INPUT_EVENT_DOWN_REPEAT:
                    music_player.executeCommand(PlayerCommand::NEXT_TRACK);
                    break;
                case InputEvent::INPUT_EVENT_RIGHT:
                    current_screen = AppScreen::SCREEN_VOLUME_CONTROL;
                    break;
                case InputEvent::INPUT_EVENT_LEFT:
                    current_screen = AppScreen::SCREEN_TRACK_SELECTION;
                    break;
                case InputEvent::INPUT_EVENT_ENTER:
                case InputEvent::INPUT_EVENT_ENTER_LONG_PRESS:
                    if (music_player.getState() == PlayerState::PLAYING) {
                        music_player.executeCommand(PlayerCommand::PAUSE);
                    } else {
                        music_player.executeCommand(PlayerCommand::PLAY);
                    }
                    break;
                default: break;
            }
            break;
        }

        case AppScreen::SCREEN_VOLUME_CONTROL: {
            switch (event) {
                case InputEvent::INPUT_EVENT_UP:
                case InputEvent::INPUT_EVENT_UP_LONG_PRESS:
                case InputEvent::INPUT_EVENT_UP_REPEAT:
                    bluetooth_manager.volumeUp();
                    break;
                case InputEvent::INPUT_EVENT_DOWN:
                case InputEvent::INPUT_EVENT_DOWN_LONG_PRESS:
                case InputEvent::INPUT_EVENT_DOWN_REPEAT:
                    bluetooth_manager.volumeDown();
                    break;
                case InputEvent::INPUT_EVENT_RIGHT:
                    current_screen = AppScreen::SCREEN_BLUETOOTH_SELECTION;
                    break;
                case InputEvent::INPUT_EVENT_LEFT:
                    current_screen = AppScreen::SCREEN_NOW_PLAYING;
                    break;
                case InputEvent::INPUT_EVENT_ENTER:
                    current_screen = AppScreen::SCREEN_NOW_PLAYING;
                    break;
                default: break;
            }
            break;
        }
    }

    // Check for Bluetooth connection event to trigger screen transition
    if (bluetooth_manager.hasConnectionEvent()) {
        if (current_screen == AppScreen::SCREEN_BLUETOOTH_SELECTION){
            current_screen = AppScreen::SCREEN_NOW_PLAYING;
        }
        bluetooth_manager.consumeConnectionEvent();
    }

    // Poll for remote volume changes (from headphones/speaker)
    if (bluetooth_manager.hasVolumeChanged()) {
        bluetooth_manager.consumeVolumeChangeEvent();
        // Display will automatically update with new volume on next update()
    }

    display_manager.update(current_screen);
    delay(100);
}

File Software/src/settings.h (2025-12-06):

#ifndef SETTINGS_H
#define SETTINGS_H

// =================================================================================
// HARDWARE CONFIGURATION
// =================================================================================
// Define here your board version
// Uncomment only one of the following lines to select the hardware configuration
#define DEV_BOARD_REV_1_0
// #define CUSTOM_BOARD


// =================================================================================
// GENERAL SETTINGS
// =================================================================================

#define SERIAL_BAUD_RATE 115200

// --- Splash Screen ---
#define SHOW_SPLASH_SCREEN true // Set to false to disable splash screen
#define SPLASH_SCREEN_DURATION 1500 // Milliseconds to display splash screen

// --- Menu Settings ---
#define MENU_SCROLL_DELAY 500 // Milliseconds to wait before starting to scroll long text
#define MENU_SCROLL_SPEED 75 // Milliseconds per pixel shift for scrolling text

// -- Splash Screen Logo (56x56px)
#define LOGO_WIDTH 56
#define LOGO_HEIGHT 56
const unsigned char splash_screen_logo[] PROGMEM = {
    0x80, 0xff, 0xff, 0xff, 0xff, 0xff, 0x01, 0xe0, 0xff, 0xff, 0xff, 0xff, 0xff, 0x07, 0xf0, 0xff, 
    0xff, 0xff, 0xff, 0xff, 0x0f, 0xf8, 0xff, 0xff, 0xff, 0xff, 0xff, 0x1f, 0xfc, 0xff, 0xff, 0xff, 
    0xff, 0xff, 0x3f, 0xfe, 0xff, 0x1f, 0xfe, 0xff, 0xff, 0x7f, 0xfe, 0xff, 0x1f, 0xfe, 0xff, 0xff, 
    0x7f, 0xff, 0xff, 0x1f, 0xfe, 0xff, 0xe1, 0xff, 0xff, 0xff, 0x1f, 0xfe, 0xff, 0xe1, 0xff, 0xff, 
    0xff, 0x1f, 0xfe, 0xff, 0xe1, 0xff, 0xff, 0x87, 0x1f, 0xfe, 0xff, 0xe1, 0xff, 0xff, 0x87, 0x1f, 
    0x7e, 0xf8, 0xe1, 0xff, 0xff, 0x87, 0x1f, 0x7e, 0xf8, 0xe1, 0xff, 0xff, 0x87, 0x10, 0x7e, 0xf8, 
    0xe1, 0xff, 0x3f, 0x84, 0x10, 0x7e, 0x08, 0xe1, 0xff, 0x3f, 0x84, 0x10, 0x7e, 0x08, 0x21, 0xfc, 
    0x3f, 0x84, 0x10, 0x7e, 0x08, 0x21, 0xfc, 0x3f, 0x84, 0x10, 0x42, 0x08, 0x21, 0xfc, 0x3f, 0x84, 
    0x10, 0x42, 0x08, 0x21, 0xfc, 0x3f, 0x84, 0x10, 0x42, 0x08, 0x21, 0xfc, 0x3f, 0x84, 0x10, 0x42, 
    0x08, 0x21, 0xfc, 0xff, 0xff, 0xff, 0xff, 0xff, 0xff, 0xff, 0xff, 0xff, 0xff, 0xff, 0xff, 0xff, 
    0xff, 0xff, 0xff, 0xff, 0xff, 0xff, 0xff, 0xff, 0xff, 0xff, 0xff, 0xff, 0xff, 0xff, 0xff, 0x0f, 
    0x78, 0xf0, 0x81, 0x0f, 0x3f, 0xfc, 0x0f, 0x38, 0xe0, 0x01, 0x07, 0x1e, 0xf8, 0xcf, 0x3f, 0xe7, 
    0x19, 0x67, 0x9e, 0xf1, 0xcf, 0x3f, 0xff, 0x39, 0x7f, 0xfe, 0xf3, 0xcf, 0x3f, 0xfe, 0x39, 0x7f, 
    0xfe, 0xf3, 0x0f, 0x7c, 0xf8, 0x19, 0x3f, 0xff, 0xf1, 0x0f, 0xfc, 0xf0, 0x01, 0x3f, 0xff, 0xf8, 
    0xcf, 0xff, 0xe3, 0x81, 0x7f, 0x7e, 0xfc, 0xcf, 0xff, 0xe7, 0xf9, 0x7f, 0x3e, 0xfe, 0xcf, 0x3f, 
    0xe7, 0xf9, 0x67, 0x1e, 0xff, 0x0f, 0x38, 0xe0, 0xf9, 0x07, 0x1e, 0xf0, 0x0f, 0x78, 0xf0, 0xf9, 
    0x0f, 0x1f, 0xf0, 0xff, 0xff, 0xff, 0xff, 0xff, 0xff, 0xff, 0xff, 0xff, 0xff, 0xff, 0xff, 0xff, 
    0xff, 0xff, 0xff, 0xff, 0xff, 0xff, 0xff, 0xff, 0xff, 0x3f, 0xcf, 0x81, 0x0f, 0xff, 0xff, 0xff, 
    0x3f, 0xc6, 0x01, 0x07, 0xfe, 0xff, 0xff, 0x3f, 0xc0, 0x19, 0x67, 0xfe, 0xff, 0xff, 0x3f, 0xc0, 
    0x39, 0x7f, 0xfe, 0xff, 0xff, 0x3f, 0xc9, 0x39, 0x7f, 0xfe, 0xff, 0xff, 0x3f, 0xcf, 0x19, 0x3f, 
    0xff, 0xff, 0xff, 0x3f, 0xcf, 0x01, 0x3f, 0xff, 0xff, 0xff, 0x3f, 0xcf, 0x81, 0x7f, 0xfe, 0xff, 
    0xff, 0x3f, 0xcf, 0xf9, 0x7f, 0xfe, 0xff, 0xfe, 0x3f, 0xcf, 0xf9, 0x67, 0xfe, 0x7f, 0xfe, 0x3f, 
    0xcf, 0xf9, 0x07, 0xfe, 0x7f, 0xfc, 0x3f, 0xcf, 0xf9, 0x0f, 0xff, 0x3f, 0xf8, 0xff, 0xff, 0xff, 
    0xff, 0xff, 0x1f, 0xf0, 0xff, 0xff, 0xff, 0xff, 0xff, 0x0f, 0xe0, 0xff, 0xff, 0xff, 0xff, 0xff, 
    0x07, 0x80, 0xff, 0xff, 0xff, 0xff, 0xff, 0x01
};


// =================================================================================
// DEV BOARD V1.0 CONFIGURATION
// =================================================================================
#if defined(DEV_BOARD_REV_1_0)

// Target Bluetooth device name
#define TARGET_DEVICE_NAME "Lenovo LP40"

// Music root directory on SD card
#define MUSIC_ROOT "/"

// --- SPI BUS ---
#define SPI_MISO 26
#define SPI_MOSI 33
#define SPI_SCK  25

// --- SD Card ---
#define SD_CS_PIN 22

// --- OLED Display ---
#define OLED_DC    27
#define OLED_RESET 14
#define OLED_CS    12
#define SCREEN_WIDTH 128
#define SCREEN_HEIGHT 64
// Define the U8g2 constructor for your display. This allows you to easily change the
// display type in the future.
// Full list of supported constructors: https://github.com/olikraus/u8g2/wiki/u8g2setupcpp
#define U8G2_DISPLAY_TYPE U8G2_SSD1306_128X64_NONAME_F_4W_HW_SPI
// Define the arguments for the U8g2 constructor.
// This must match the constructor chosen in U8G2_DISPLAY_TYPE.
// For 4-wire hardware SPI: U8G2_R2 (rotation), CS, DC, RST
#define U8G2_CONSTRUCTOR_ARGS U8G2_R2, OLED_CS, OLED_DC, OLED_RESET
// These macros define the exact U8g2 class and its constructor arguments
// The final display instance will be created as `U8G2_DISPLAY_TYPE u8g2(U8G2_CONSTRUCTOR_ARGS);`
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

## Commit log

2025-12-01 PoC of buttons and OLED display
2025-12-01 modularized buttons and display code
2025-12-01 improved SPI initialization
2025-12-03 switched to U8g2 library for the display
2025-12-06 improved input management with long and repeated button press
2025-12-06 switch to using buttons in U8g2
2025-12-06 added automatic switch to NOW_PLAYING menu when connected
2025-12-08 added project of devboard rev1.0
    [Buttons.kicad_sch, Display.kicad_sch, ESP32-WROOM-32E-N8.STEP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]
2025-12-08 added project of devboard Rev1.1
    [Buttons.kicad_sch, Display.kicad_sch, ESP32-WROOM-32E-N8.STEP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]
2025-12-08 fixed switch footprint and changed buttons pins to avoid bootstrapping pins
    [Buttons.kicad_sch, ESP32MP3-dev-board.kicad_pcb, MCU.kicad_sch]
2026-01-27 added cache to track name to improve performance
